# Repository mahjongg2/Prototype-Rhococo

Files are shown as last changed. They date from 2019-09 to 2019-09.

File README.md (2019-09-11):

# Prototype-Rhococo
Prototype of my Retro Home color computer, a 8-bit Z80 based home computer remake with 128 (bank switched) RAM, that uses a Parallax propeller chip for all the stuff that homecomputers from the previous century did with lots of simple CMOS logic circuits and sometimes dedicated VLSI chips did, such as generating TV pictures, and sound.
My rhococo should be able to generate 27 colors of VGA video in 512 x 480 resolution, and should be able to generate PSG quality sound. 
instead of relying on cassette tapes, of floppy-disks, it can use SD-cards. It doesn't store its permanent memory on (E)PROMS but on a serial EEPROM read out by the propeller,and copied to Z80 RAM at boot time. 
Its not based on any one retro computer but borrows ideas from all of them, mainly from the sinclair spectrum, Commodore 64, and MSX computers.

on these page I will commit CAD files, (main page is Rhococo.sch with sub-schematics Z80CPU+RAM.sch, and KEYBOARD.sch, and RHOCOCO.kicad.PCB for the layout) , but eventually I will also upload ideas, code and other stuff so that others can also build and test prototypes of my retro home computer.

Note that I explicitly call this a prototype, as Rhococo is still in development, and not a fully functioning device.
Lots of things are not even tested yet, as for testing them other stuff must work first.

If hardware bugs are found I will upload updated files fo new PCBś, and/or information to patch existing PCB's.

Weekly updated information and progress reports will be posted on my Wiki at: https://revspace.nl/Designing_the_RhoCoCo_Retro_Home_COlor_COmputer_hardware

if you want to discuss this meaterial with me, the best place for now would be here: https://www.raspberrypi.org/forums/viewtopic.php?f=62&t=226889

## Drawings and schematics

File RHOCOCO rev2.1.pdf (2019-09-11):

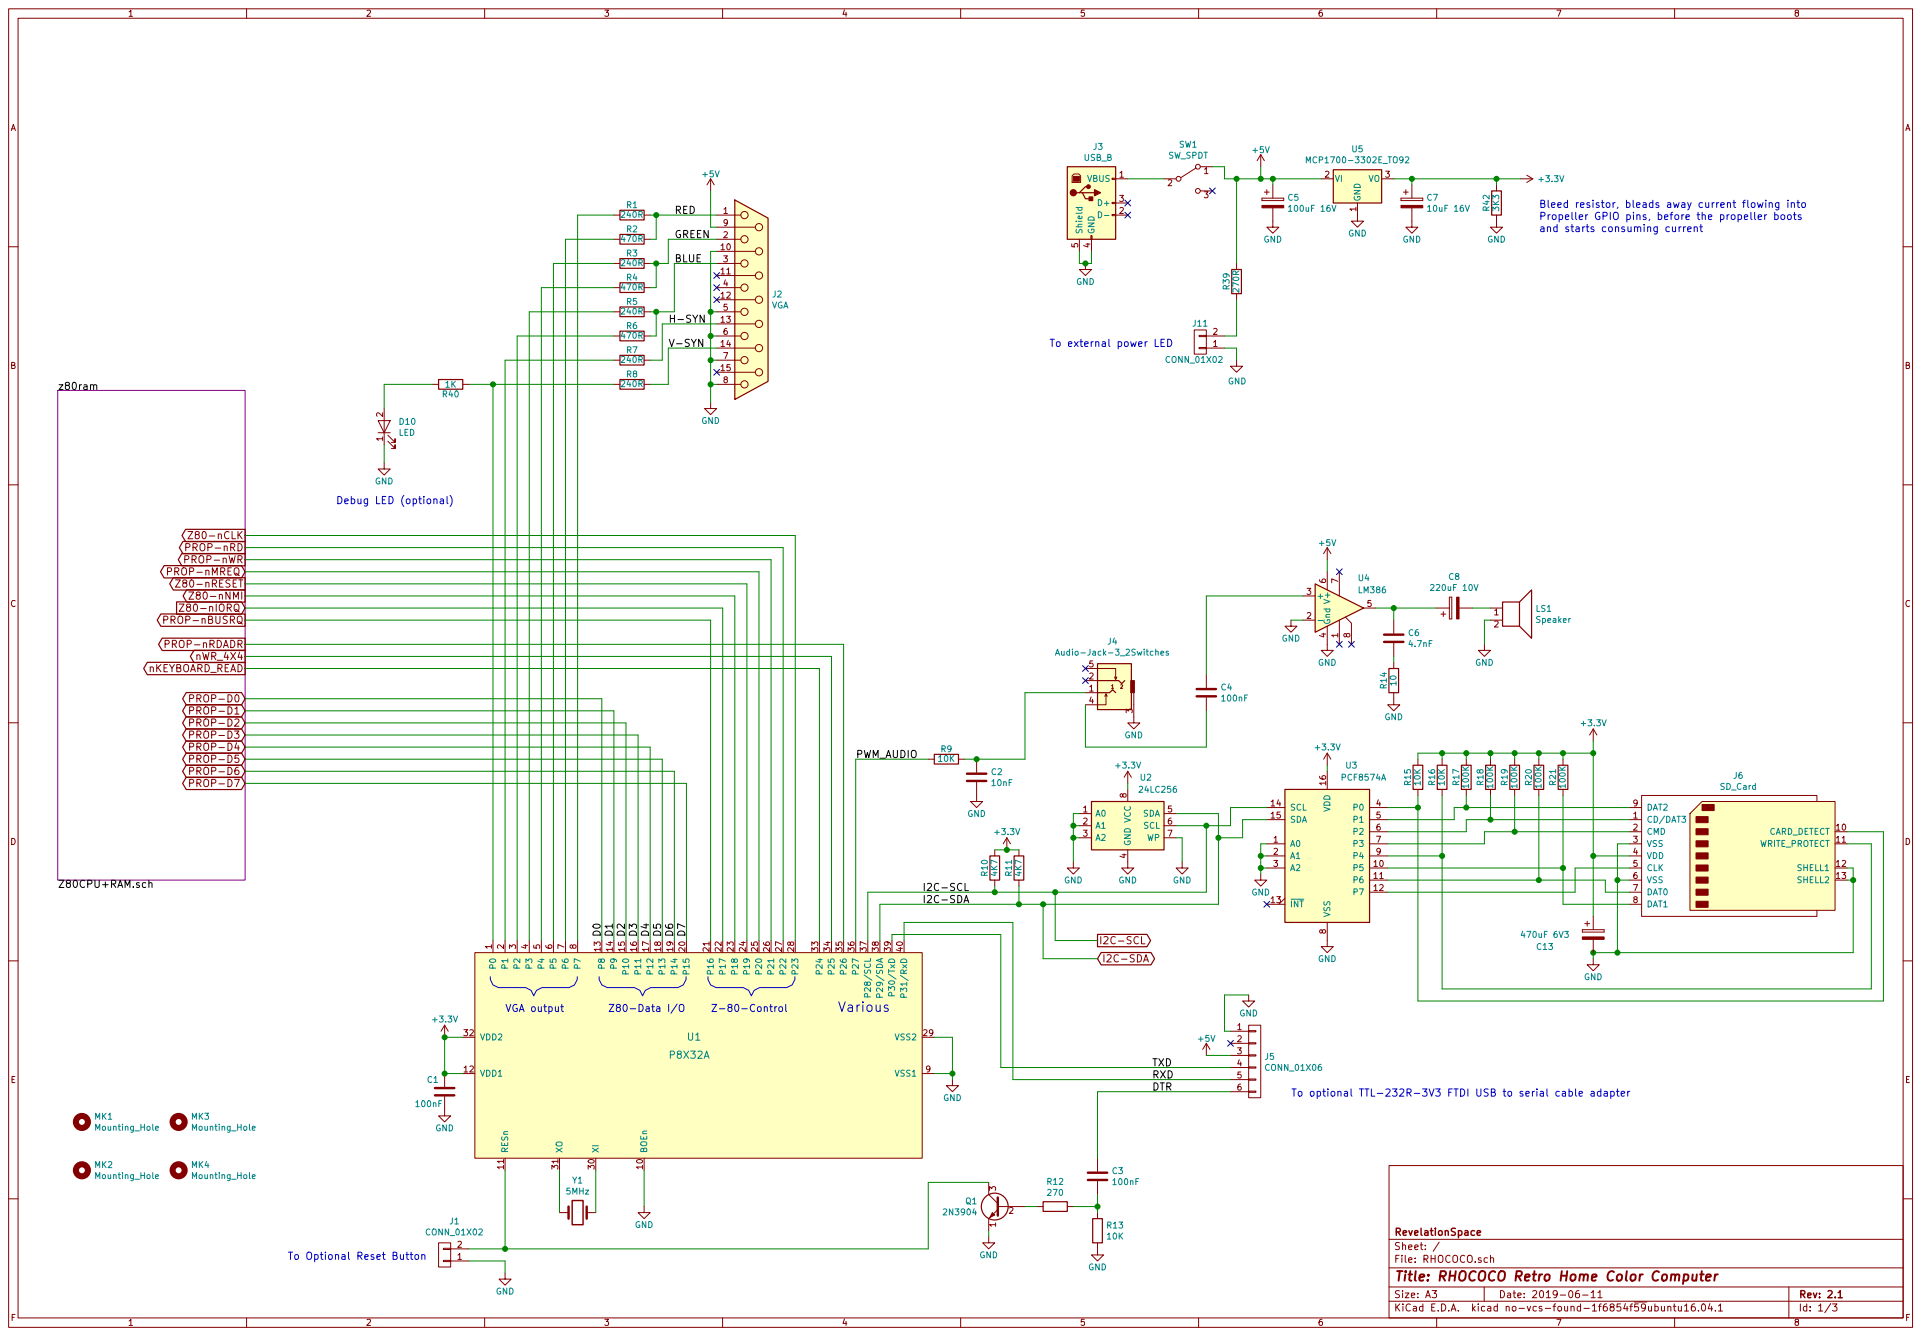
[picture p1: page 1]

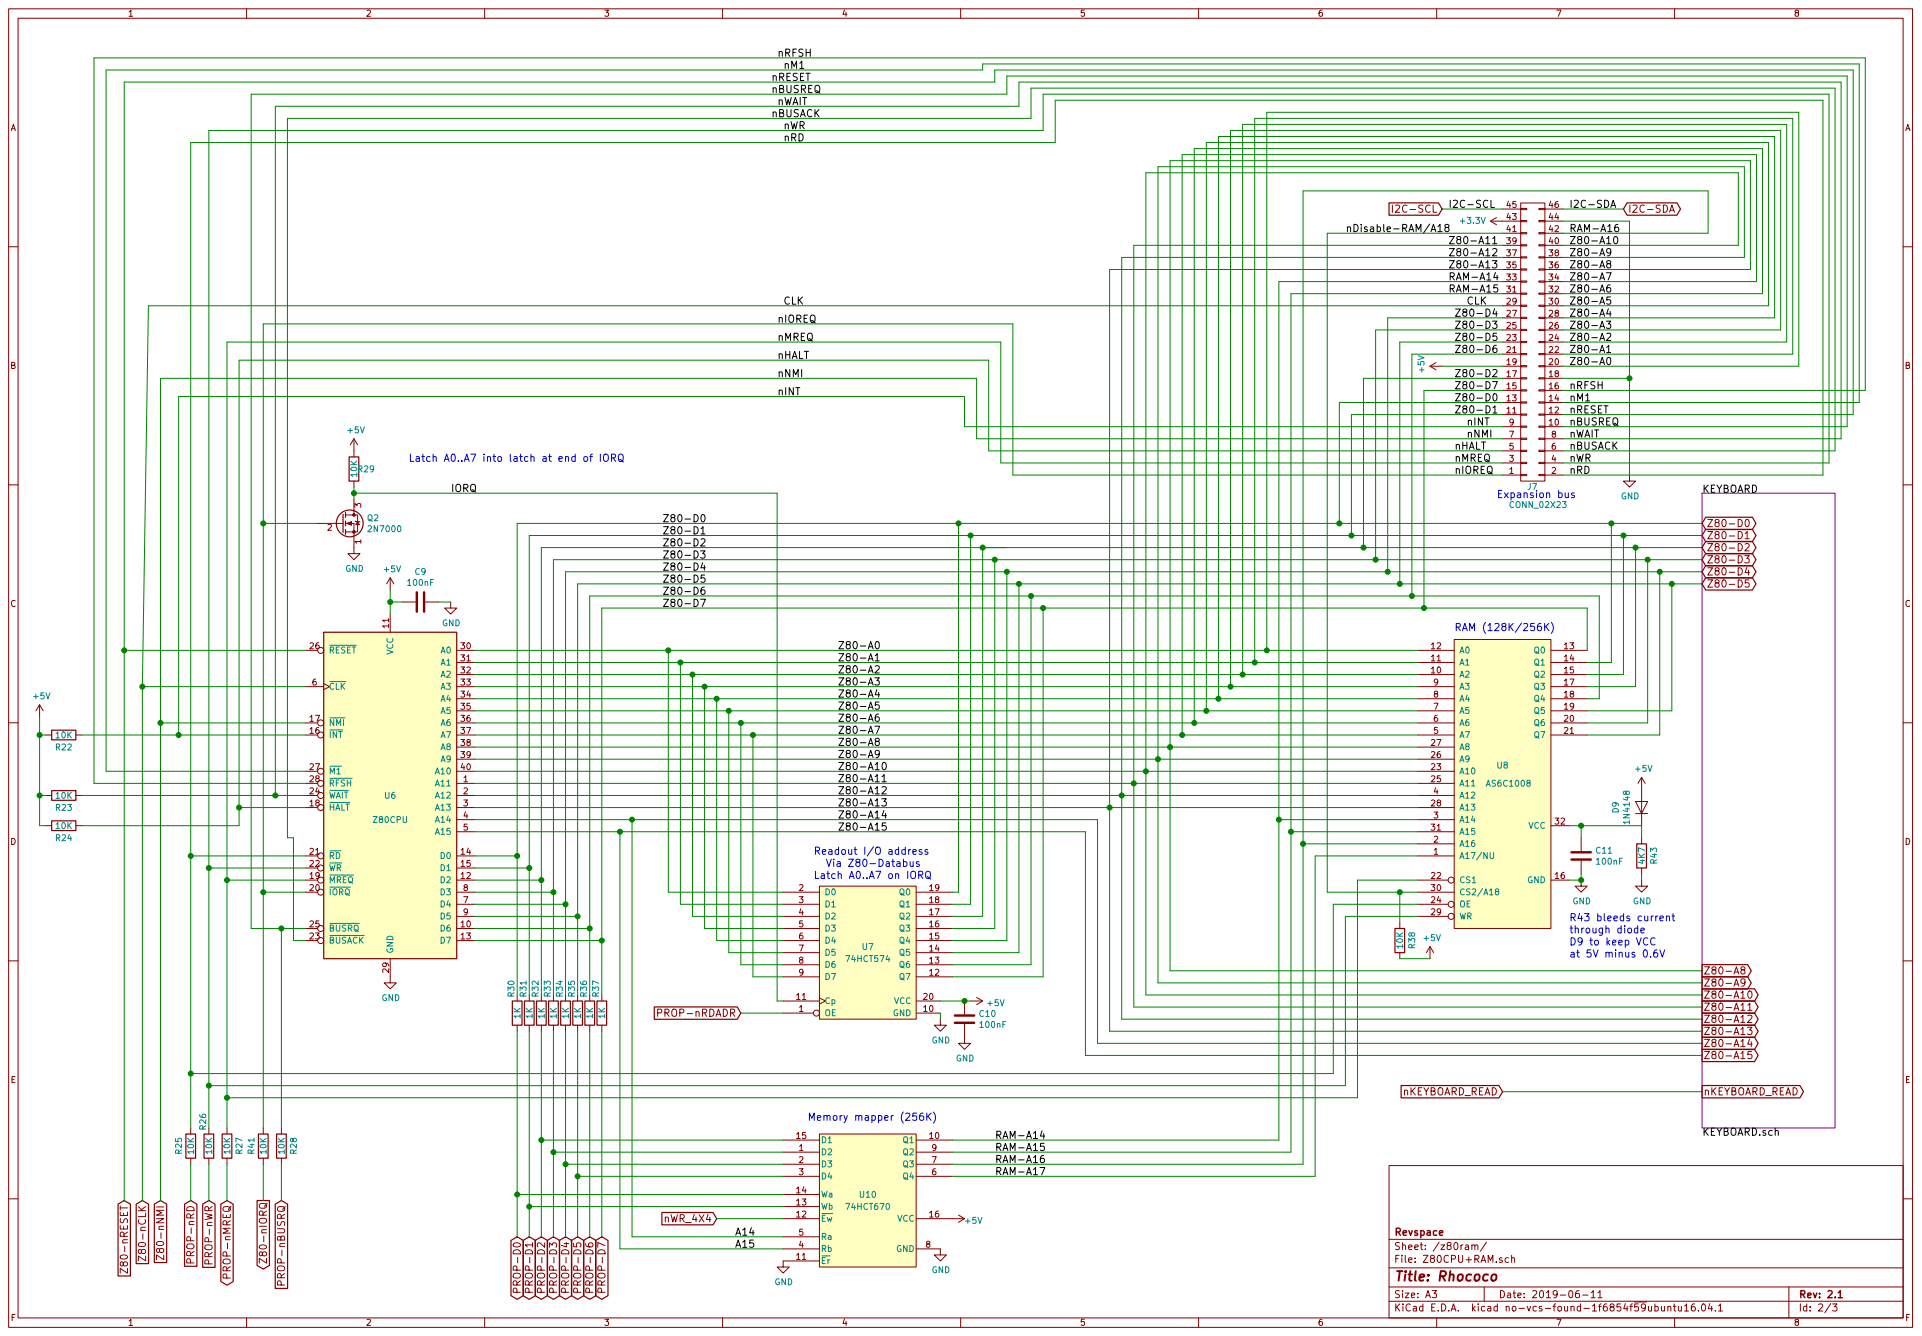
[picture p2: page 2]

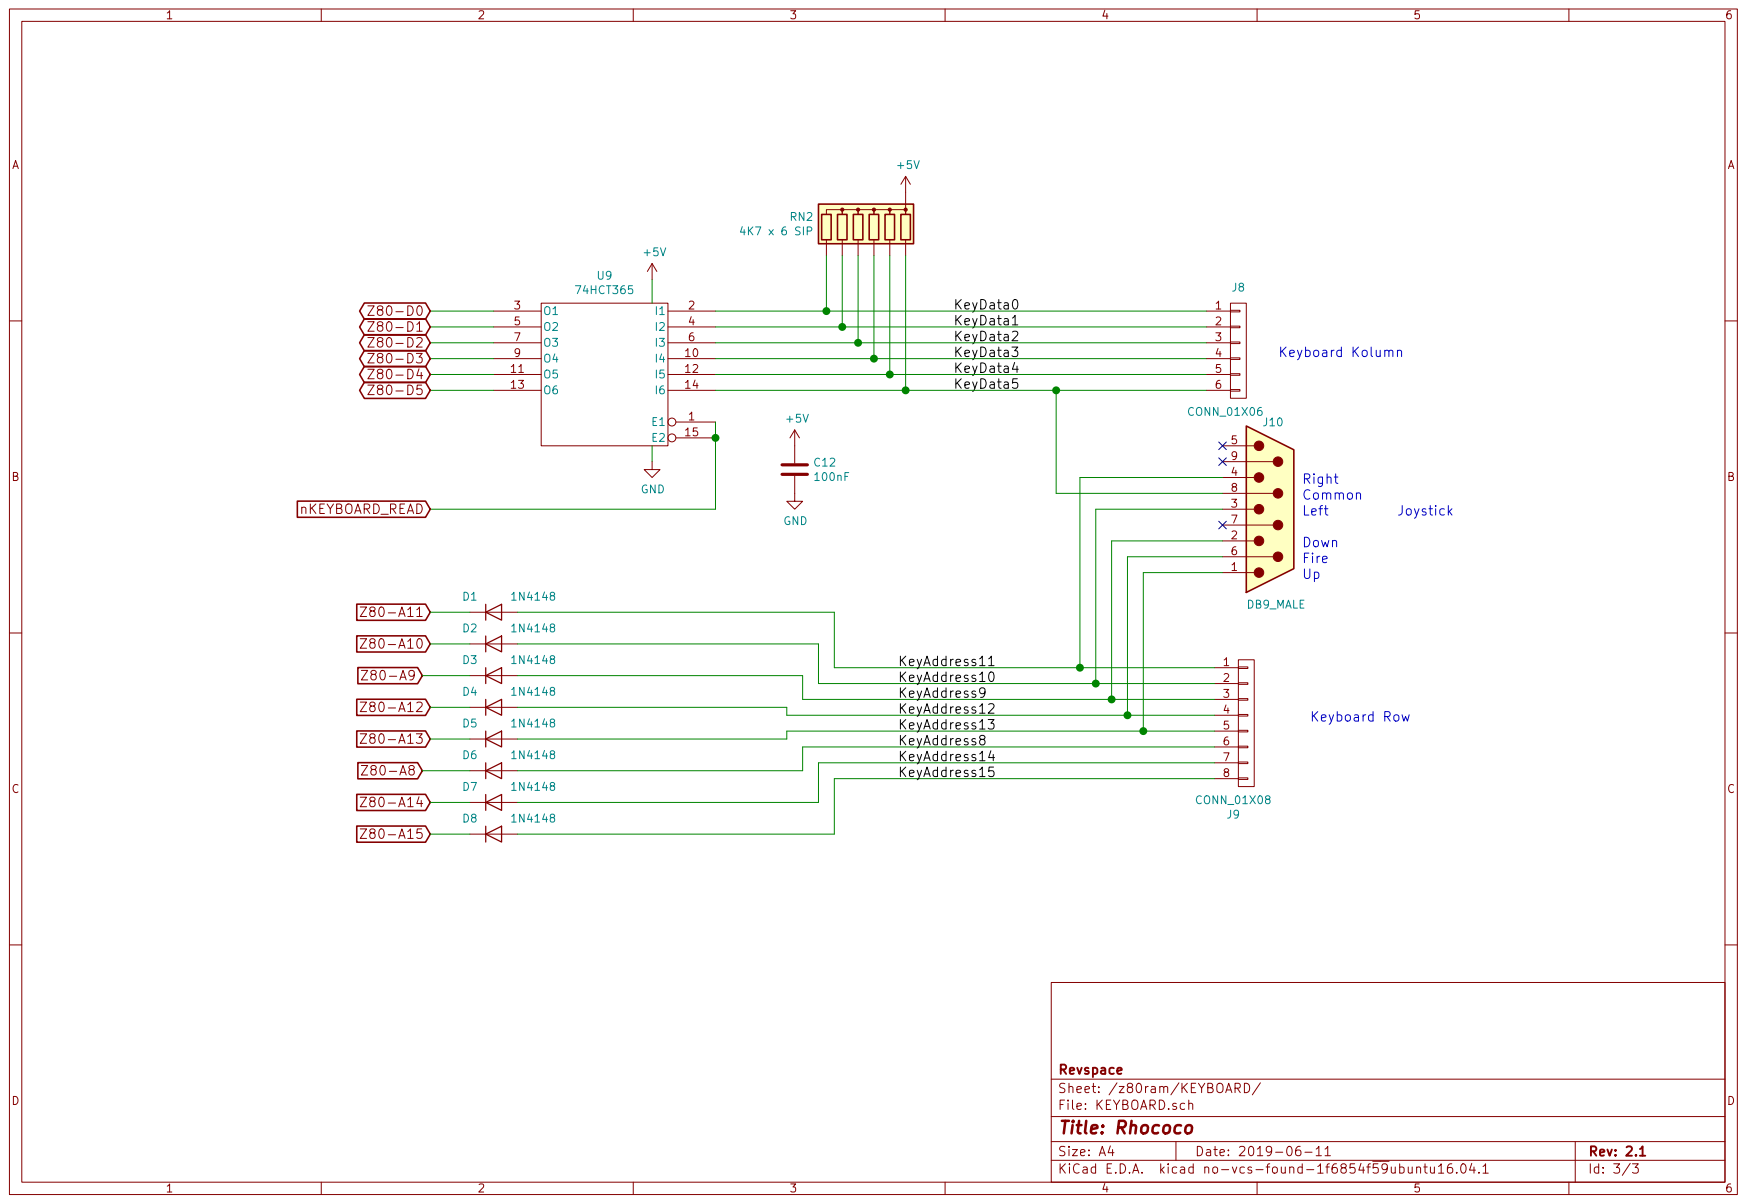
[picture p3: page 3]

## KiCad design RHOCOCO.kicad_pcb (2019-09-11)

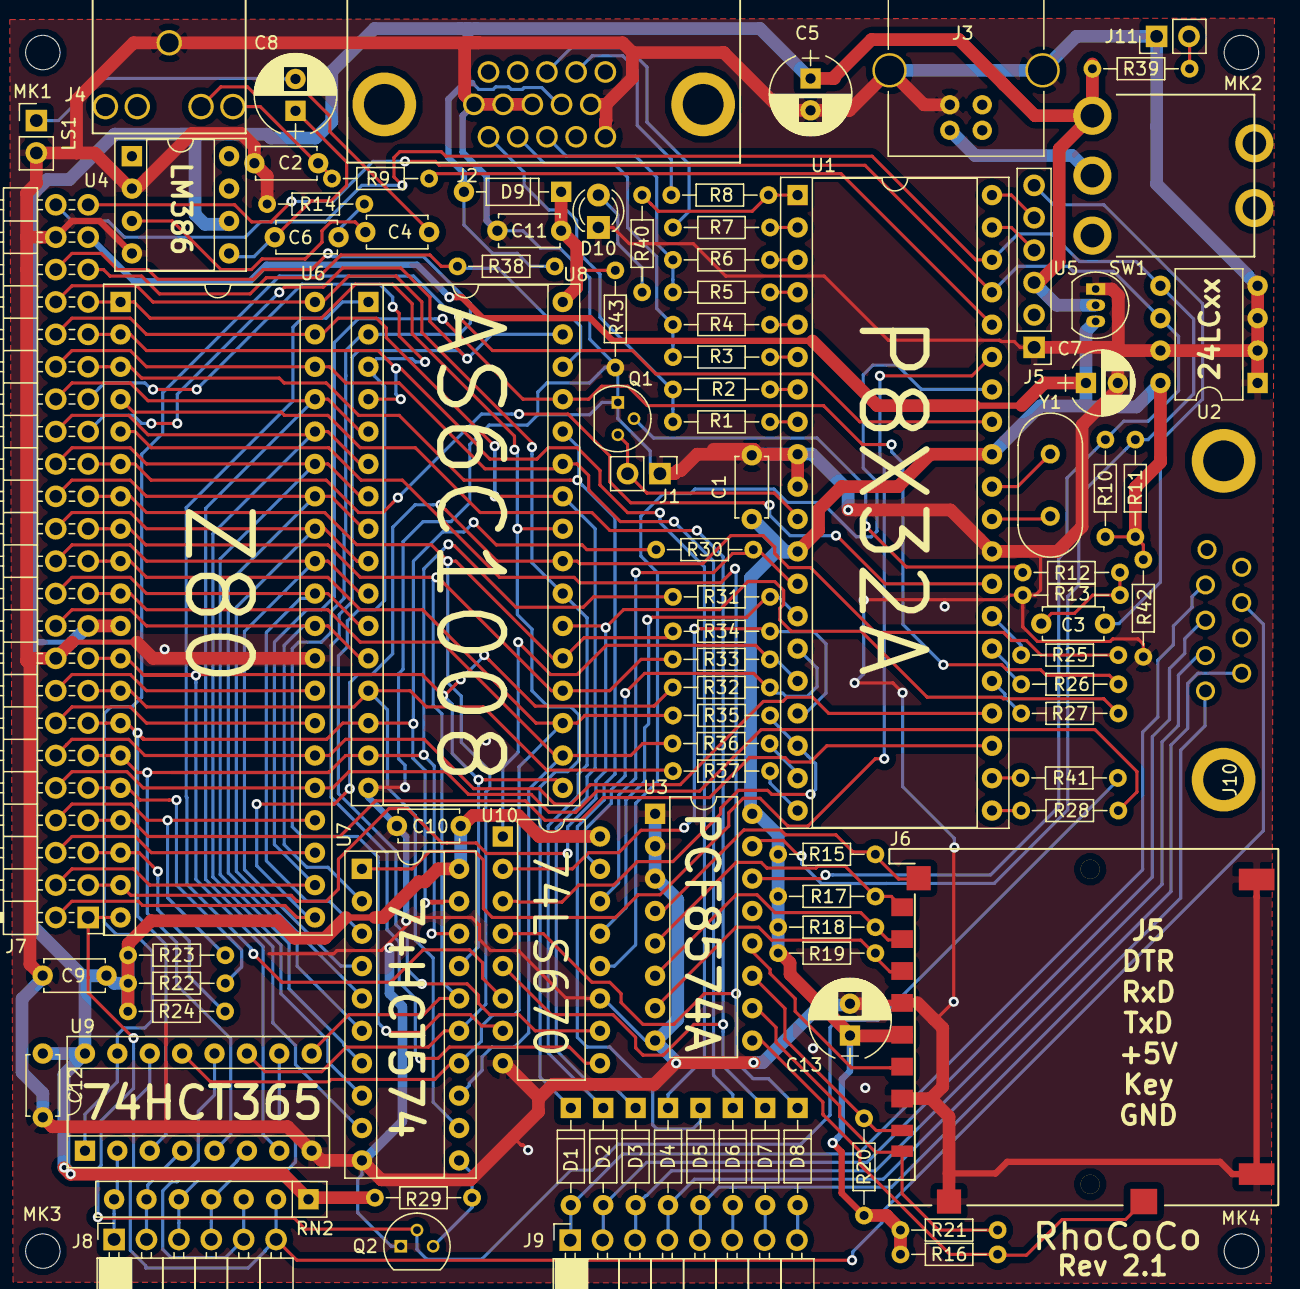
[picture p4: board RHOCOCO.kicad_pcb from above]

Board: 2 copper layers, 97 parts (0 on the bottom side), 119 nets.

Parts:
C1, C3, C4, C9, C10, C11, C12: 100nF; C_Disc_D4.7mm_W2.5mm_P5.00mm
C2: 10nF; C_Disc_D4.7mm_W2.5mm_P5.00mm
C5: 100uF 16V; CP_Radial_D6.3mm_P2.50mm
C6: 4.7nF; C_Disc_D4.7mm_W2.5mm_P5.00mm
C7: 10uF 16V; CP_Radial_D5.0mm_P2.50mm
C8, C13: 220uF 10V; CP_Radial_D6.3mm_P2.50mm
D1, D2, D3, D4, D5, D6, D7, D8, D9: 1N4148; D_DO-35_SOD27_P7.62mm_Horizontal
D10: LED; LED_D3.0mm
J1, J11: CONN_01X02; Pin_Header_Straight_1x02_Pitch2.54mm
J2: VGA; VGA_connector
J3: USB_B
J4: Audio-Jack-3_2Switches; SPC21348
J5: CONN_01X06; Pin_Header_Straight_1x06_Pitch2.54mm
J6: SD_Card; SD-67600-006
J7: CONN_02X23; Pin_Header_Angled_2x23_Pitch2.54mm
J8: CONN_01X06; Socket_Strip_Angled_1x06_Pitch2.54mm
J9: CONN_01X08; Socket_Strip_Angled_1x08_Pitch2.54mm
J10: DB9_MALE; dB09-MALE
LS1: Speaker; Pin_Header_Straight_1x02_Pitch2.54mm
MK1, MK2, MK3, MK4: Mounting_Hole; MountingHole_2.7mm_M2.5
Q1: 2N3904; TO-92_Molded_Narrow
Q2: 2N7000; TO-92_Molded_Narrow
R1, R3, R5, R7, R8: 240R; R_Axial_DIN0204_L3.6mm_D1.6mm_P7.62mm_Horizontal
R2, R4, R6: 470R; R_Axial_DIN0204_L3.6mm_D1.6mm_P7.62mm_Horizontal
R9, R13, R15, R16, R22, R23, R24, R25, R26, R27, R28, R29, R38, R41: 10K; R_Axial_DIN0204_L3.6mm_D1.6mm_P7.62mm_Horizontal
R10, R11, R43: 4K7; R_Axial_DIN0204_L3.6mm_D1.6mm_P7.62mm_Horizontal
R12: 270; R_Axial_DIN0204_L3.6mm_D1.6mm_P7.62mm_Horizontal
R14: 10; R_Axial_DIN0204_L3.6mm_D1.6mm_P7.62mm_Horizontal
R17, R18, R19, R20, R21: 100K; R_Axial_DIN0204_L3.6mm_D1.6mm_P7.62mm_Horizontal
R30, R31, R32, R33, R34, R35, R36, R37, R40: 1K; R_Axial_DIN0204_L3.6mm_D1.6mm_P7.62mm_Horizontal
R39: 270R; R_Axial_DIN0204_L3.6mm_D1.6mm_P7.62mm_Horizontal
R42: 3K3; R_Axial_DIN0204_L3.6mm_D1.6mm_P7.62mm_Horizontal
RN2: 4K7 x 6 SIP; R_Array_SIP7
SW1: SW_SPDT; SWITCH-300SP1J1BLKM6QE
U1: P8X32A; DIP-40_W15.24mm_Socket
U2: 24LC256; DIP-8_W7.62mm
U3: PCF8574A; DIP-16_W7.62mm
U4: LM386; DIP-8_W7.62mm_Socket
U5: MCP1700-3302E_TO92; TO-92_Inline_Narrow_Oval
U6: Z80CPU; DIP-40_W15.24mm_Socket
U7: 74HCT574; DIP-20_W7.62mm_Socket
U8: AS6C1008; DIP-32_W15.24mm_Socket
U9: 74HCT365; DIP-16_W7.62mm_Socket
U10: 74HCT670; DIP-16_W7.62mm
Y1: 5MHz; Crystal_HC49-U_Vertical

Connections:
+3V3: C1.1, C7.1, C13.1, J6.4, J7.43, R10.2, R11.2, R15.2, R16.2, R17.2, R18.2, R19.2, R20.2, R21.2, R42.2, U1.12, U1.32, U2.8, U3.16, U5.3
+5V: C5.1, C9.2, C10.1, C12.1, D9.2, J2.9, J5.3, J7.19, R22.2, R23.2, R24.2, R29.1, R38.2, R39.2, RN2.1, SW1.1, U4.6, U5.2, U6.11, U7.20, U9.16, U10.16
/BLUE: J2.3, R5.2, R6.2
/DTR: C3.1, J5.6
/GREEN: J2.2, R3.2, R4.2
/H-SYN: J2.13, R7.2
/PWM_AUDIO: R9.1, U1.36
/RED: J2.1, R1.2, R2.2
/RXD: J5.5, U1.40
/TXD: J5.4, U1.39
/V-SYN: J2.14, R8.2
/z80ram/IORQ: Q2.3, R29.2, U7.11
/z80ram/KEYBOARD/KeyAddress8: D6.2, J9.6
/z80ram/KEYBOARD/KeyAddress9: D3.2, J9.3, J10.2
/z80ram/KEYBOARD/KeyAddress10: D2.2, J9.2, J10.3
/z80ram/KEYBOARD/KeyAddress11: D1.2, J9.1, J10.4
/z80ram/KEYBOARD/KeyAddress12: D4.2, J9.4, J10.6
/z80ram/KEYBOARD/KeyAddress13: D5.2, J9.5, J10.1
/z80ram/KEYBOARD/KeyAddress14: D7.2, J9.7
/z80ram/KEYBOARD/KeyAddress15: D8.2, J9.8
/z80ram/KEYBOARD/KeyData0: J8.1, RN2.7, U9.2
/z80ram/KEYBOARD/KeyData1: J8.2, RN2.6, U9.4
/z80ram/KEYBOARD/KeyData2: J8.3, RN2.5, U9.6
/z80ram/KEYBOARD/KeyData3: J8.4, RN2.4, U9.10
/z80ram/KEYBOARD/KeyData4: J8.5, RN2.3, U9.12
/z80ram/KEYBOARD/KeyData5: J8.6, J10.8, RN2.2, U9.14
/z80ram/RAM-A14: J7.33, U8.3, U10.10
/z80ram/RAM-A15: J7.31, U8.31, U10.9
/z80ram/RAM-A16: J7.42, U8.2, U10.7
/z80ram/RAM-A17: U8.1, U10.6
/z80ram/Z80-A0: J7.20, U6.30, U7.2, U8.12
/z80ram/Z80-A1: J7.22, U6.31, U7.3, U8.11
/z80ram/Z80-A2: J7.24, U6.32, U7.4, U8.10
/z80ram/Z80-A3: J7.26, U6.33, U7.5, U8.9
/z80ram/Z80-A4: J7.28, U6.34, U7.6, U8.8
/z80ram/Z80-A5: J7.30, U6.35, U7.7, U8.7
/z80ram/Z80-A6: J7.32, U6.36, U7.8, U8.6
/z80ram/Z80-A7: J7.34, U6.37, U7.9, U8.5
/z80ram/Z80-D6: J7.21, R36.1, U6.10, U7.13, U8.18
/z80ram/Z80-D7: J7.15, R37.1, U6.13, U7.12, U8.13
/z80ram/nBUSACK: J7.6, U6.23
/z80ram/nBUSREQ: J7.10, R28.1, U6.25
/z80ram/nDisable-RAM/A18: J7.41, R38.1, U8.30
/z80ram/nHALT: J7.5, R24.1, U6.18
/z80ram/nINT: J7.9, R22.1, U6.16
/z80ram/nIOREQ: J7.1, Q2.2, R41.1, U6.20
/z80ram/nM1: J7.14, U6.27
/z80ram/nMREQ: J7.3, R27.1, U6.19, U8.22
/z80ram/nRD: J7.2, R25.1, U6.21, U8.24
/z80ram/nRFSH: J7.16, U6.28
/z80ram/nWAIT: J7.8, R23.1, U6.24
/z80ram/nWR: J7.4, R26.1, U6.22, U8.29
GND: C1.2, C2.2, C5.2, C7.2, C9.1, C10.2, C11.2, C12.2, C13.2, D10.1, J1.1, J2.5, J2.6, J2.7, J2.8, J2.10, J3.4, J3.5, J4.3, J5.1, J6.3, J6.6, J6.12, J6.13, J7.18, J7.44, J11.1, LS1.2, Q1.1, Q2.1, R13.2, R14.1, R42.1, R43.2, U1.9, U1.10, U1.29, U2.1, U2.2, U2.3, U2.4, U2.7, U3.1, U3.2, U3.3, U3.8, U4.2, U4.4, U5.1, U6.29, U7.10, U8.16, U9.8, U10.8, U10.11
I2C-SCL: J7.45, R10.1, U1.37, U2.6, U3.14
I2C-SDA: J7.46, R11.1, U1.38, U2.5, U3.15
unnamed: C2.1, J4.1, R9.2
unnamed: C3.2, R12.1, R13.1
unnamed: C4.1, U4.3
unnamed: C4.2, J4.4
unnamed: C6.1, C8.1, U4.5
unnamed: C6.2, R14.2
unnamed: C8.2, LS1.1
unnamed: C11.1, D9.1, R43.1, U8.32
unnamed: D10.2, R40.2
unnamed: J1.2, Q1.3, U1.11
unnamed: J3.1, SW1.2
unnamed: J6.1, R18.1, U3.6
unnamed: J6.2, R19.1, U3.7
unnamed: J6.5, U3.12
unnamed: J6.7, R20.1, U3.11
unnamed: J6.8, R21.1, U3.10
unnamed: J6.9, R17.1, U3.5
unnamed: J6.10, R15.1, U3.4
unnamed: J6.11, R16.1, U3.9
unnamed: J11.2, R39.1
unnamed: Q1.2, R12.2
unnamed: R1.1, U1.8
unnamed: R2.1, U1.7
unnamed: R3.1, U1.6
unnamed: R4.1, U1.5
unnamed: R5.1, U1.4
unnamed: R6.1, U1.3
unnamed: R7.1, U1.2
unnamed: R8.1, R40.1, U1.1
unnamed: U1.30, Y1.2
unnamed: U1.31, Y1.1
PROP-D0: R30.2, U1.13, U10.14
PROP-D1: R31.2, U1.14, U10.13
PROP-D2: R32.2, U1.15, U10.15
PROP-D3: R33.2, U1.16, U10.1
PROP-D4: R34.2, U1.17, U10.2
PROP-D5: R35.2, U1.18, U10.3
PROP-D6: R36.2, U1.19
PROP-D7: R37.2, U1.20
PROP-nBUSRQ: R28.2, U1.21
PROP-nMREQ: R27.2, U1.25
PROP-nRD: R25.2, U1.27
PROP-nRDADR: U1.35, U7.1
PROP-nWR: R26.2, U1.26
Z80-A8: D6.1, J7.36, U6.38, U8.27
Z80-A9: D3.1, J7.38, U6.39, U8.26
Z80-A10: D2.1, J7.40, U6.40, U8.23
Z80-A11: D1.1, J7.39, U6.1, U8.25
Z80-A12: D4.1, J7.37, U6.2, U8.4
Z80-A13: D5.1, J7.35, U6.3, U8.28
Z80-A14: D7.1, U6.4, U10.5
Z80-A15: D8.1, U6.5, U10.4
Z80-D0: J7.13, R30.1, U6.14, U7.19, U8.14, U9.3
Z80-D1: J7.11, R31.1, U6.15, U7.18, U8.15, U9.5
Z80-D2: J7.17, R32.1, U6.12, U7.17, U8.17, U9.7
Z80-D3: J7.25, R33.1, U6.8, U7.16, U8.20, U9.9
Z80-D4: J7.27, R34.1, U6.7, U7.15, U8.21, U9.11
Z80-D5: J7.23, R35.1, U6.9, U7.14, U8.19, U9.13
Z80-nCLK: J7.29, U1.28, U6.6
Z80-nIORQ: R41.2, U1.22
Z80-nNMI: J7.7, U1.23, U6.17
Z80-nRESET: J7.12, U1.24, U6.26
nKEYBOARD_READ: U1.33, U9.1, U9.15
nWR_4X4: U1.34, U10.12

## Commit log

2019-09-11 Add files via upload
    The latest schematics (revision 4.0 September 2019)
2019-09-11 Add files via upload
    Gerber and drill files to produce Rhococo prototype PCB's updated to september 2019 (rev 2.1)
2019-09-11 Add files via upload
    KiCad schematic files
    [KEYBOARD.sch, RHOCOCO.sch, Z80CPU+RAM.sch]
2019-09-11 Add files via upload
    Rhococo rev 2.1 layout file
    [RHOCOCO.kicad_pcb]
